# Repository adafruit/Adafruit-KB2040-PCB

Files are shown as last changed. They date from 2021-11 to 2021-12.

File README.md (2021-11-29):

## Adafruit KB2040 - RP2040 Kee Boar Driver PCB

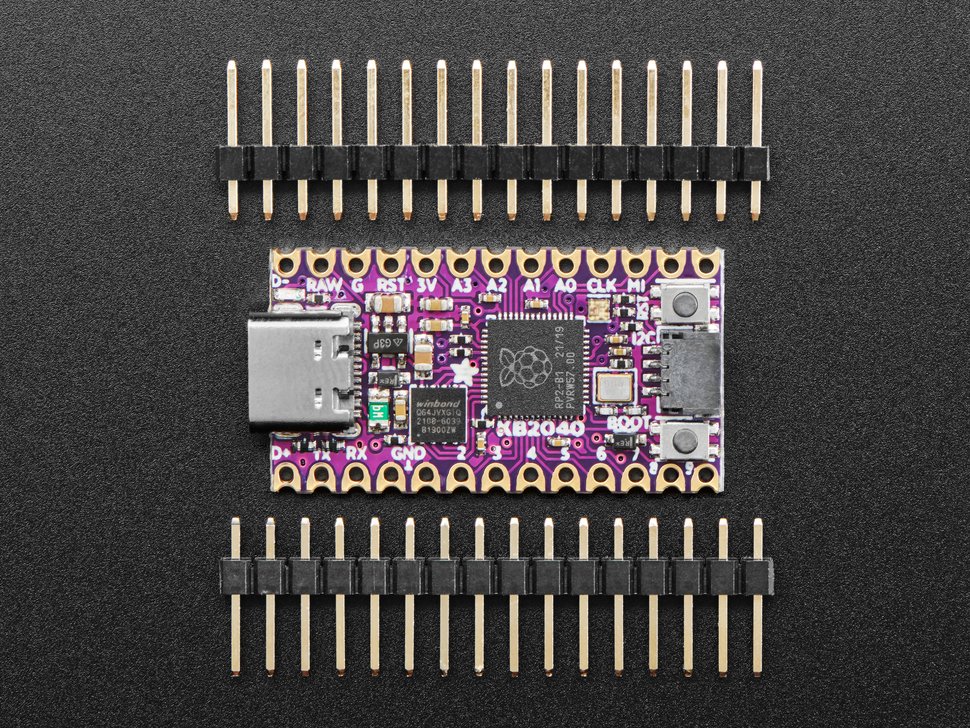
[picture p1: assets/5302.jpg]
<a href="http://www.adafruit.com/products/5302"><br/>
Click here to purchase one from the Adafruit shop</a>

PCB files for the Adafruit KB2040 - RP2040 Kee Boar Driver. 

Format is EagleCAD schematic and board layout
* https://www.adafruit.com/product/5302

### Description

A wild Kee Boar appears! It’s a shiny KB2040! An Arduino Pro Micro-shaped board for Keebs with RP2040. (#keeblife 4 evah) A lot of folks like using Adafruit parts for their Keeb builds – but with the ItsyBitsy not being pin-compatible with the Pro Micro pinout, it really wasn't very easy without some sort of adapter plate.

Now we’re seeing lots of people use CircuitPython for keebs, which is awesome! So why not try our hands at spinning up a pro-micro-compatible RP2040 board? The RP2040 is plenty powerful, low-cost, and makes for an excellent keeb driver chip.

We mixed together what we liked most about the SparkFun Pro Micro RP2040 (Qwiic / STEMMA QT I2C port on the end, so good!) and Elite-C (castellated pads & pins for D+ and D-) and our existing RP2040 boards (boot button can be used for user, 8MB QSPI flash, onboard NeoPixel, jumper for skipping the diode/fuse for high power RGB LEDs or USB hosting). We even got it to all fit on a 2-layer PCB with 7/7 routing – just needed to make the smallest caps and resistors 0402. 

With 20 GPIO available (18 on castellated pins, 2 on STEMMA QT port) you can easily make up to 100-keys matrices, or common 65% 5x15 layouts. Use a plug-and-play QT cable to connect to the last two pins without having to do any desoldering/rework.

### License

Adafruit invests time and resources providing this open source design, please support Adafruit and open-source hardware by purchasing products from [Adafruit](https://www.adafruit.com)!

Designed by Limor Fried/Ladyada for Adafruit Industries.

Creative Commons Attribution/Share-Alike, all text above must be included in any redistribution. 
See license.txt for additional details.

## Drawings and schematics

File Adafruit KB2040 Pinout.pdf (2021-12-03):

# Adafruit KB2040

# https://www.adafruit.com/product/5302

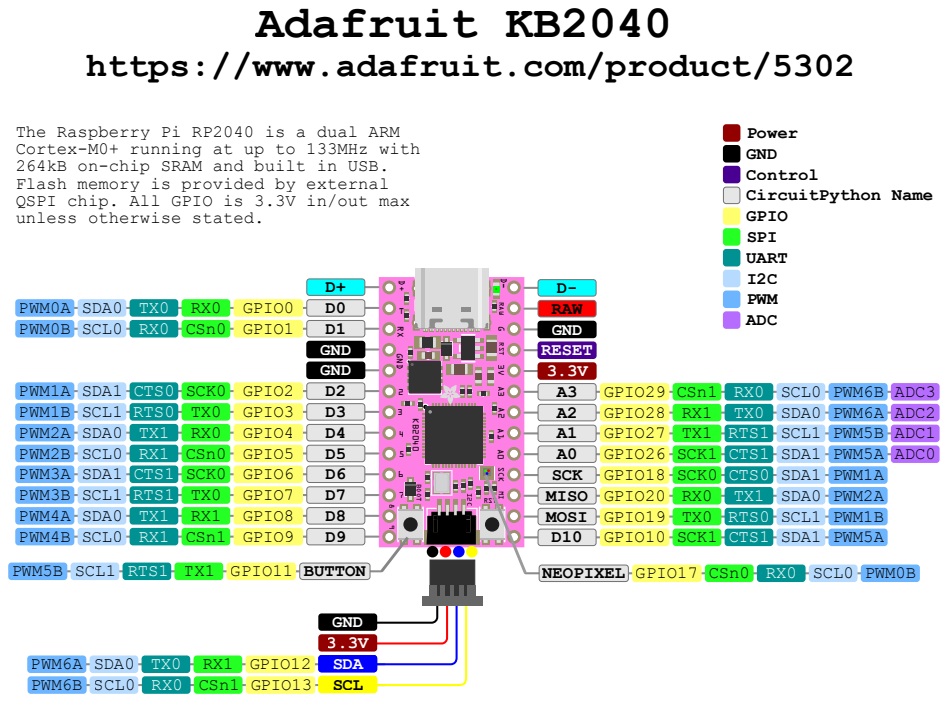
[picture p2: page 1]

The Raspberry Pi RP2040 is a dual ARM
Cortex-M0+ running at up to 133MHz with
264kB on-chip SRAM and built in USB.
Flash memory is provided by external
QSPI chip. All GPIO is 3.3V in/out max
unless otherwise stated.

MI A0 A1 A2 A3 3V RST G RAW D- SCK

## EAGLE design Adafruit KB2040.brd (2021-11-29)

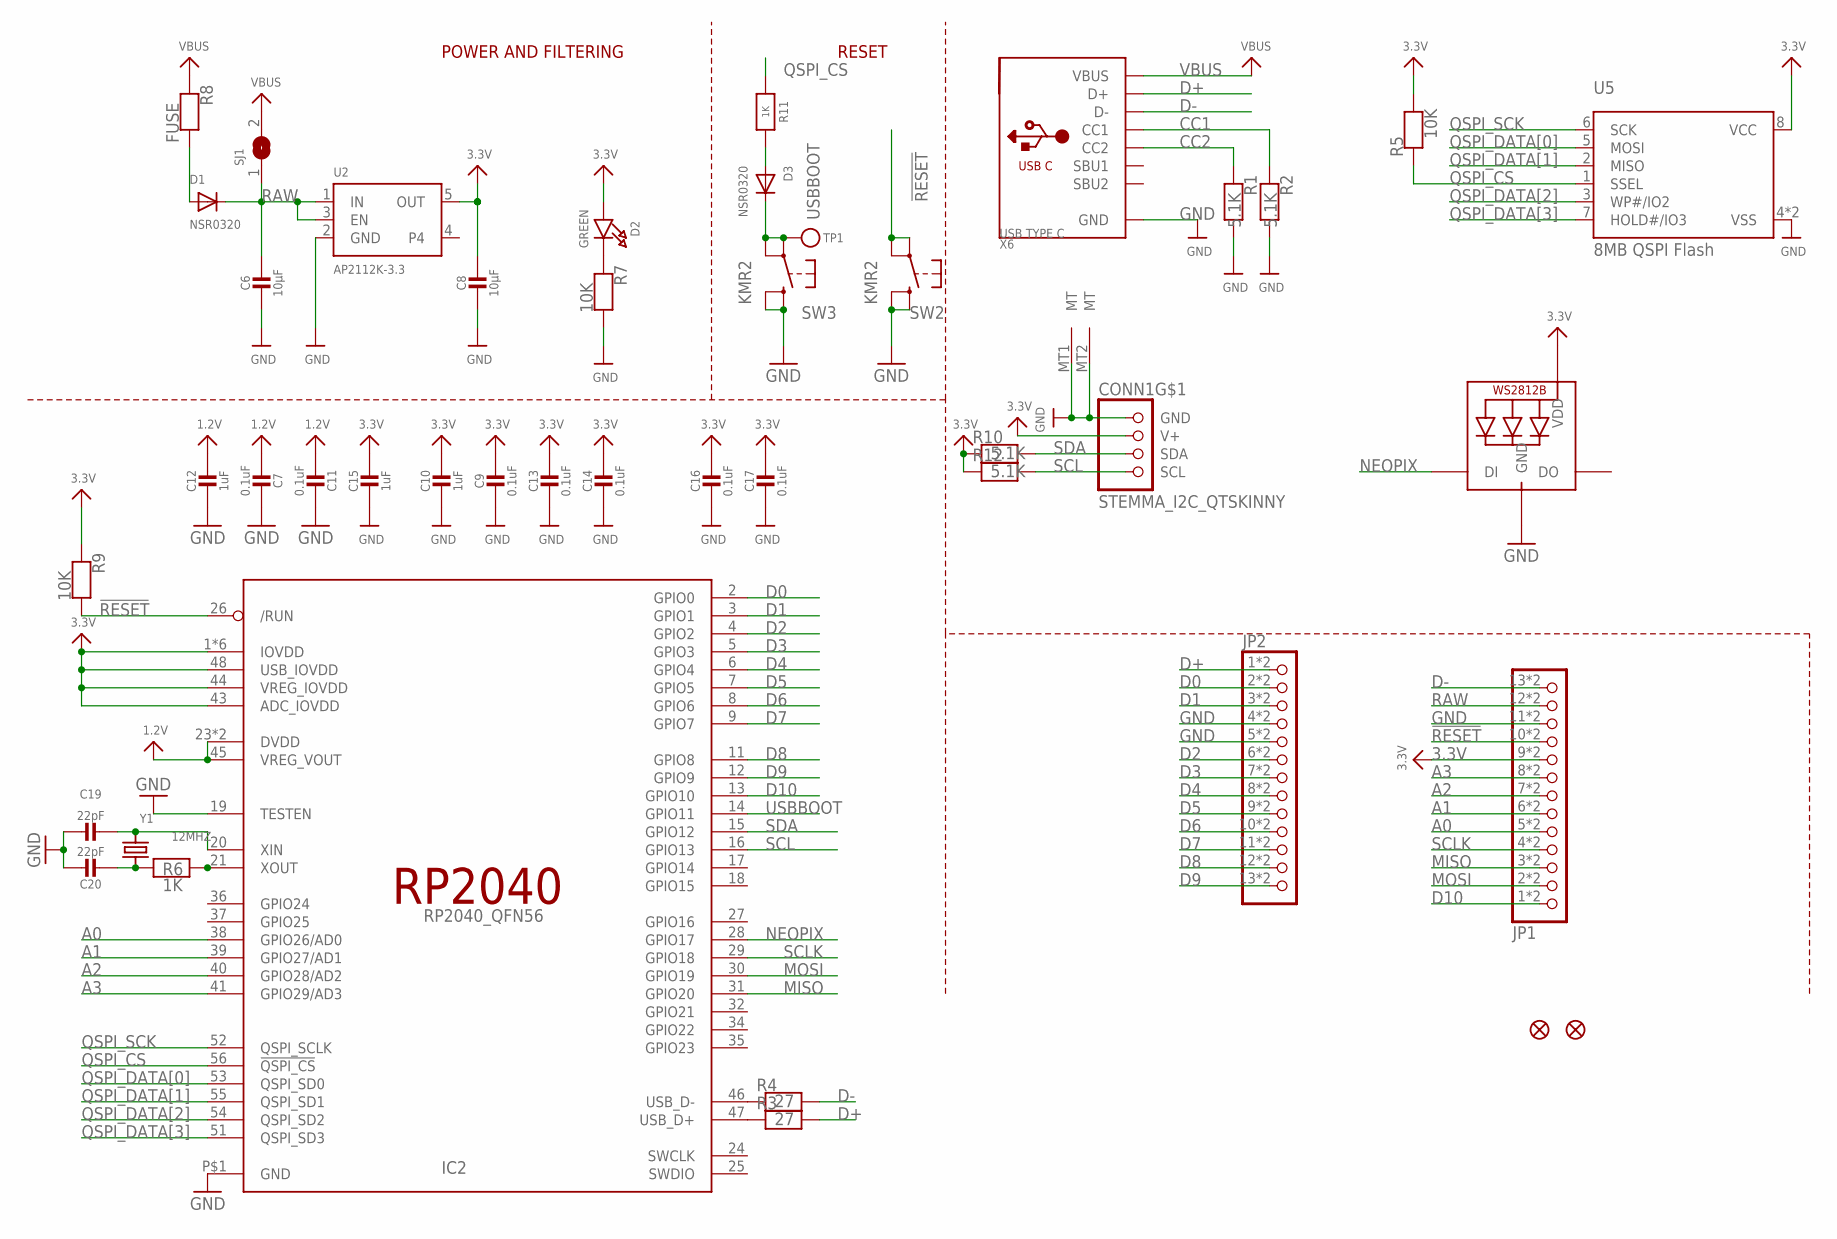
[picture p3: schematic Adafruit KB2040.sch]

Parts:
C6, C8: 10µF; _0805MP
C7, C9, C11, C13, C14, C16, C17: 0.1uF; _0402NO
C10, C12: 1uF; _0603MP
C15: 1uF; 0603-NO
C19, C20: 22pF; _0402NO
CONN1: STEMMA_I2C_QTSKINNY; JST_SH4_SKINNY
D1, D3: NSR0320; SOD-323F
D2: GREEN; CHIPLED_0603_NOOUTLINE
IC2: RP2040_QFN56; QFN56_7MM_REDUCEDEPAD
JP1, JP2: HEADER-1X13_CASTEL; 1X13_CASTEL
LED1: WS2812B_SK6805_1515; SK6805_1515
R1, R2, R10, R12: 5.1K; _0402NO
R3, R4: 27; _0402NO
R5, R7, R9: 10K; _0402NO
R6, R11: 1K; _0402NO
R8: FUSE; 0805-NO
SJ1: SOLDERJUMPER; SOLDERJUMPER_ARROW_NOPASTE
SW2, SW3: KMR2; BTN_KMR2_4.6X2.8
TP1: TESTPOINTROUND1.5MMNO; TESTPOINT_ROUND_1.5MM_NO
U2: AP2112K-3.3; SOT23-5
U5: 8MB QSPI Flash; USON8_4X4
U$34, U$35: FIDUCIAL_1MM
X6: USB TYPE C; USB_C_CUSB31-CFM2AX-01-X
Y1: 12MHZ; CRYSTAL_2.5X2

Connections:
1.2V: C7.2, C11.2, C12.1, IC2.23 (DVDD), IC2.45 (VREG_VOUT), IC2.50 (DVDD)
3.3V: C8.1, C9.1, C10.1, C13.1, C14.1, C15.1, C16.1, C17.1, CONN1.2 (V+), D2.A, IC2.1 (IOVDD), IC2.10 (IOVDD), IC2.22 (IOVDD), IC2.33 (IOVDD), IC2.42 (IOVDD), IC2.43 (ADC_IOVDD), IC2.44 (VREG_IOVDD), IC2.48 (USB_IOVDD), IC2.49 (IOVDD), JP1.9, JP1.9C (9), LED1.2 (VDD), R5.2, R9.1, R10.1, R12.1, U2.5 (OUT), U5.8 (VCC)
!RESET: IC2.26 (/RUN), JP1.10, JP1.10C (10), R9.2, SW2.A, SW2.A' (P1)
A0: IC2.38 (GPIO26/AD0), JP1.5, JP1.5C (5)
A1: IC2.39 (GPIO27/AD1), JP1.6, JP1.6C (6)
A2: IC2.40 (GPIO28/AD2), JP1.7, JP1.7C (7)
A3: IC2.41 (GPIO29/AD3), JP1.8, JP1.8C (8)
CC1: R2.1, X6.A5 (CC1)
CC2: R1.1, X6.B5 (CC2)
D0: IC2.2 (GPIO0), JP2.2, JP2.2C (2)
D1: IC2.3 (GPIO1), JP2.3, JP2.3C (3)
D2: IC2.4 (GPIO2), JP2.6, JP2.6C (6)
D3: IC2.5 (GPIO3), JP2.7, JP2.7C (7)
D4: IC2.6 (GPIO4), JP2.8, JP2.8C (8)
D5: IC2.7 (GPIO5), JP2.9, JP2.9C (9)
D6: IC2.8 (GPIO6), JP2.10, JP2.10C (10)
D7: IC2.9 (GPIO7), JP2.11, JP2.11C (11)
D8: IC2.11 (GPIO8), JP2.12, JP2.12C (12)
D9: IC2.12 (GPIO9), JP2.13, JP2.13C (13)
D10: IC2.13 (GPIO10), JP1.1, JP1.1C (1)
D+: JP2.1, JP2.1C (1), R3.2, X6.A6 (D+), X6.B6 (D+)
D-: JP1.13, JP1.13C (13), R4.2, X6.A7 (D-), X6.B7 (D-)
GND: C6.2, C7.1, C8.2, C9.2, C10.2, C11.1, C12.2, C13.2, C14.2, C15.2, C16.2, C17.2, C19.1, C20.1, CONN1.1 (GND), CONN1.MT1 (MT), CONN1.MT2 (MT), IC2.19 (TESTEN), IC2.P$1 (GND), JP1.11, JP1.11C (11), JP2.4, JP2.4C (4), JP2.5, JP2.5C (5), LED1.4 (GND), R1.2, R2.2, R7.2, SW2.B (S), SW2.B' (S1), SW3.B (S), SW3.B' (S1), U2.2 (GND), U5.4 (VSS), U5.PAD (VSS), X6.A1B12 (GND), X6.B1A12 (GND)
MISO: IC2.31 (GPIO20), JP1.3, JP1.3C (3)
MOSI: IC2.30 (GPIO19), JP1.2, JP1.2C (2)
unnamed: IC2.47 (USB_D+), R3.1
unnamed: D2.C, R7.1
unnamed: IC2.46 (USB_D-), R4.1
unnamed: D3.A, R11.2
unnamed: C19.2, IC2.20 (XIN), Y1.3 (2)
unnamed: C20.2, R6.1, Y1.1
unnamed: IC2.21 (XOUT), R6.2
unnamed: D1.A, R8.2
NEOPIX: IC2.28 (GPIO17), LED1.1 (DI)
QSPI_CS: IC2.56 (!QSPI_CS), R5.1, R11.1, U5.1 (SSEL)
QSPI_DATA[0]: IC2.53 (QSPI_SD0), U5.5 (MOSI)
QSPI_DATA[1]: IC2.55 (QSPI_SD1), U5.2 (MISO)
QSPI_DATA[2]: IC2.54 (QSPI_SD2), U5.3 (WP#/IO2)
QSPI_DATA[3]: IC2.51 (QSPI_SD3), U5.7 (HOLD#/IO3)
QSPI_SCK: IC2.52 (QSPI_SCLK), U5.6 (SCK)
RAW: C6.1, D1.C, JP1.12, JP1.12C (12), SJ1.1, U2.1 (IN), U2.3 (EN)
SCL: CONN1.4 (SCL), IC2.16 (GPIO13), R12.2
SCLK: IC2.29 (GPIO18), JP1.4, JP1.4C (4)
SDA: CONN1.3 (SDA), IC2.15 (GPIO12), R10.2
USBBOOT: D3.C, IC2.14 (GPIO11), SW3.A, SW3.A' (P1), TP1.P$1
VBUS: R8.1, SJ1.2, X6.A4B9 (VBUS), X6.B4A9 (VBUS)

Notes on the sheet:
POWER AND FILTERING
RESET

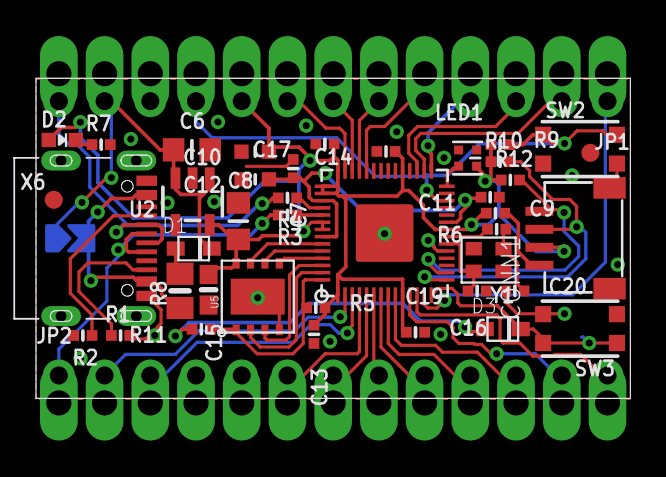
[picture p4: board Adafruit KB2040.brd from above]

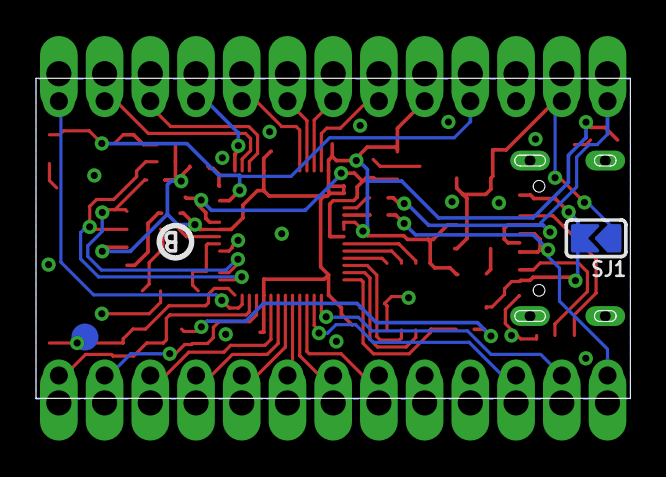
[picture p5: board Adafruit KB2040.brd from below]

Board: 2 copper layers, 33.0 x 17.8 mm, 47 parts (4 on the bottom side), 46 nets.

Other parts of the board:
U$17: KB2040_BOT
U$19: KB2040_TOP
U$20: PCBFEAT-REV-040

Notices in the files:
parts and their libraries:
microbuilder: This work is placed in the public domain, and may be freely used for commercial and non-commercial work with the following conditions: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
